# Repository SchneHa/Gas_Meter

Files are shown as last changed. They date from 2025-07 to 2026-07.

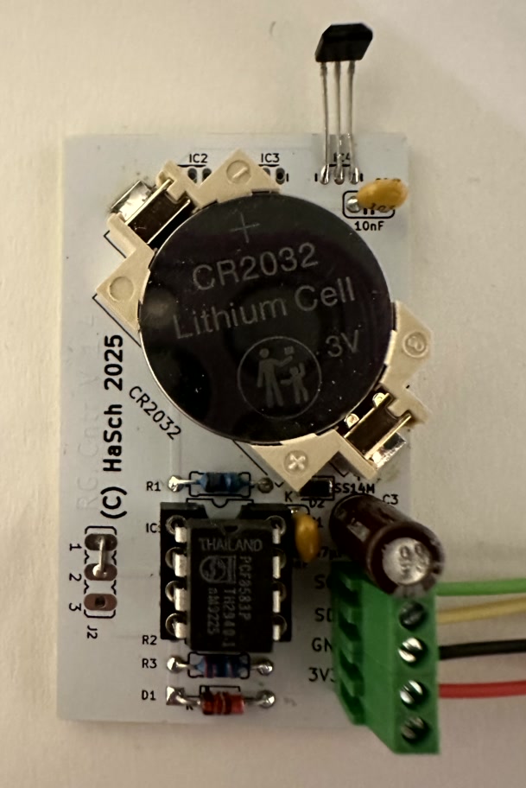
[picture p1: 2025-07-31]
Gas_Meter/pcb/V1.4/CP Gas Zähler Lesekopf.jpg

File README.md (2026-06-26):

# Gasverbrauch messen und verarbeiten 

## Funktion

Manche Gaszähler geben pro verbrauchte 10 Liter einen magnetischen Impuls ab.
Dieser Impuls wird mit einem Hall Sensor in elektrische Impulse umgewandelt, ein RTC Baustein PCF8583 arbeitet als Zähler und speichert die Zahl der Impulse im internen RAM ab.

PCB Eagle Dateien (für Version 1.3) und KiCAD Dateien (für Version 1.4) sowie Stückliste (BOM) für beide Versionen anbei.

Ich habe sowohl für die Version 1.3 als auch für die Version 1.4 noch einige Platinen übrig, bei Bedarf bitte melden:
```
PCB unbestückt: 5€
PCB mit Bauteilen: 15€
PCB fertig bestückt (ohne Knopfzelle und Hallsensor noch nicht bestückt): 20€
D1 mini ESP8266: 10€
inklusive Versand innerhalb Deutschlands
hans(dot)schneider(at)gmx(dot)ch
```

Die Daten werden mit Hilfe eines ESP8266 (z.B. Wemos D1 mini) über die I²C Schnittstelle ausgelesen und verarbeitet. 
Über das MQTT Protokoll werden die Daten an einen lokalen Broker weitergeleitet, Daten werden nicht ins Internet hochgeladen, es sei denn, man richtet die Verarbeitung über Thingspeak explizit ein.
Eine 3 Volt Knopfzelle versorgt den Baustein mit Energie und erhält die Daten bei Stromausfall. In der Version 1.4 wird der Sensor durch den ESP8266 versorgt, die Knopfzelle arbeitet als Backup Batterie.

* Diese Daten werden im RTC RAM gespeichert

1. Zählimpulse
2. Zählerstand zu Beginn der Messung (Counts=0)
3. Zählerstand zu Beginn der Abrechnungsperiode
4. monatlicher Verbrauch in m³
5. Datum und Uhrzeit des letzen Auslesens des RTC Bausteins

* Diese Daten werden über MQTT an den Broker gesendet

1. Uhrzeit 
2. Gesamtverbrauch in kWh
3. aktuelle Leistung in kW
4. Anzahl der Impulse seit Reset
5. Gesamtverbrauch in m³
6. Zählerstand zu Beginn der Messung (Counts=0) in Liter
7. Zählerstand zu Begin der Abrechnungsperiode in Liter
8. nach Bedarf monatlicher Verbrauch
9. Täglicher Verbrauch in l, kWh und m³
10. Status (OK wenn Zugriff auf den RTC Baustein möglich)

* Diese Daten/Kommandos können vom Broker an den ESP8266 gesendet werden

1. Veröffentliche den Verbrauch eines einzelnen Monats oder aller Monate von 1 to 12 
 * SYNTAX  : "Energy/Gas/command"
 * PAYLOAD : "Monat, x"
 * Wert für x: entweder 1 bis 12 für einen einzelnen Monat, oder x > 12 für alle 12 Monate
  
 2. Setze den Wert für den Verbrauch zu Beginn der Heizperiode 
 * SYNTAX  : "Energy/Gas/command"
 * PAYLOAD : "InitP, x"
 * Wert für x: Verbrauch in Litern

 3. Setze den initialen Verbrauchswert für den Counter Null 
 * SYNTAX  : "Energy/Gas/command"
 * PAYLOAD : "InitS, x"
 * Wert für x: Verbrauch in Litern

 4. Setze den initialen Wert für den Verbrauch eines einzelnen Monats  
 * SYNTAX  : "Energy/Gas/command"
 * PAYLOAD : "InitM, x ; y"
 * value for x: ausgewählter Monat
 * value for y: Verbrauch in Litern
 
 5. Setze den Wert für den Start der Abrechnungsperiode 
 * Initialisiert den RTC chip und setzt den initialen Verbrauchswert für count=0 der Abrechnungsperiode 
 * SYNTAX  : "Energy/Gas/command"
 * PAYLOAD : "InitC, x"
 * value for x: Verbrauch in Litern

 6. Setze den Tageszähler zurück auf Null 
 * Setzt den aktuellen Verbrauchswert für den Tageszähler auf 0 zurück 
 * SYNTAX  : "Energy/Gas/command"
 * PAYLOAD : "InitD"

## Vorbereitung

* in Gas_WiFi SSID und Passwort eintragen
* für ArduinoOTA (Firmware Update **O**ver **T**he **A**ir) hashed Wert eines gewählte Passortes eintragen, der Hash-Wert kann z.B. über https://hash-generieren.de/ oder https://www.md5hashgenerator.com/ oder https://www.hexhero.com/tools/sha256-hash-generator gebildet werden.    
* in Gas_MQTT IP Adresse des MQTT Broker eintragen
* ggfs. Thingspeak aktivieren und Channelnummer und Key eintragen
* Topic für MQTT an die eigenen Wünsche anpassen

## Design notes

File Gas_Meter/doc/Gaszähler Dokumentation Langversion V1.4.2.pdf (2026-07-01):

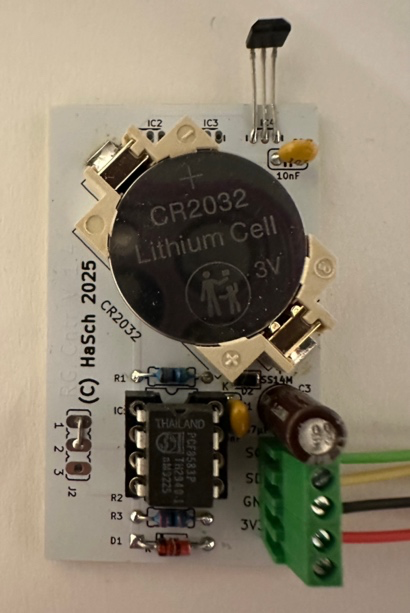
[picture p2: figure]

Abbildung 1: Gaszähler
Lesekopf V1.4

Gaszähler auslesen
Daten gegen Verlust absichern

Anders als Smart Meter zum Messen der elektrischen Arbeit speichern herkömmliche Gaszähler den gemessenen Verbrauch mechanisch in einem Zählwerk.

Ein direktes Auslesen des Verbrauchs ist etwa mit Hilfe einer Kamera und Bildanalyse möglich, der Aufwand aber recht hoch.

Viele Gaszähler geben einen magnetischen Impuls pro Umdrehung der 2. oder 3. Stelle hinter dem Komma, ab. Meistens ist das 1 Impuls pro 10 Liter (2. Stelle). In der Regel steht das auch auf dem Typenschild.

Das Zählen der Impulse erlaubt also, den Verbrauch zu ermitteln, allerdings nicht den absoluten Wert, sondern nur den Wert seit Beginn der Zählung.

Im Folgenden wird ein Lesekopf mit Speichermöglichkeit und Auswertung über einen ESP8266 Mikrocontroller beschrieben.

Hardware:

Um die Zählimpulse auch bei einem Stromausfall zu speichern, fiel die Wahl auf einen RTC CMOS Baustein, der auch als Zähler eingesetzt werden kann und 240 Bytes an RAM bietet:

PCF8583 von Philips

Der PCF8583 ist zwar recht alt aber immer noch in Stückzahlen im DIL8 Gehäuse zu haben.
Der Baustein hat ein I²C Interface und kann einfach über einen ESP8266 ausgelesen werden, der dann auch die weitere Verarbeitung übernimmt.
Mit einer Stromaufnahme von typisch 10µA bei 5 Volt und SCL inaktiv reicht eine CR2032 3-Volt Knopfzelle für lange Zeit. Das Auslesen über I²C ist bis hinunter zu 2,5 Volt Betriebsspannung möglich, der interne Zähler funktioniert laut Datenblatt sogar bis zu 1 Volt.
Für die Erfassung der Zählimpulse kann entweder ein Reed Schalter oder ein Hall-Effekt Sensor verwendet werden. Da aber Reed Schalter zum Prellen neigen und aufwendig hardwaremäßig entprellt werden müssten, fiel die Wahl auf einen Hall-Effekt Sensor. Auch hier sind die Anforderungen niedrige Stromaufnahme und Funktion bis herunter zu 2,5 Volt Betriebsspannung.

AH3661UA 2.4 - 5.4 V/DC Messbereich: -0.007 - +0.007

Mit einer Stromaufnahme von typisch 2µA im Ruhezustand bei 2,4 Volt und einem pull-up Widerstand von 0,5 bis 1 MOhm sind die Anforderungen voll erfüllt. Zusammen mit recht hochohmigen pull-up Widerständen für SDA und SCL war die gemessene Stromaufnahme bei der Musterplatine zwischen 8 und 14µA.

Eine kleine Platine mit Standard Bauteilen kann so in die Aufnahme unterhalb des Zählwerkes gesteckt werden, dass der Sensor genau unter der Stelle mit dem Magneten positioniert ist.

Zum Auslesen der Daten wird ein ESP8266 verwendet, der über das lokale WiFi Netzwerk die Daten zur Auswertung weiterreicht.

Software:

Es liegt nahe, den Speicher des RTC-Bausteins für mehr als das Abspeichern der gezählten Impulse zu nutzen, auf diese Weise kann man die Daten der Abrechnungsperiode nachhalten.
Für die Programmierung des ESP8266 habe ich die Arduino IDE 2.3.9 und die Bibliotheken Wire, time, Esp8266WiFi, PicoMQTT, Thingspeak und ArduinoOTA verwendet, alle lassen sich über die Bibliotheksverwaltung herunterladen, soweit nicht schon vorhanden

Hier ist das Speichermodell für das CMOS RAM (wurde in der Version 1.4.2 aus Gründen des knappen Speicherplatzes verschlankt):

ADDRESS_OLD_COUNTER | //hält den letzten Stand der Auslesung mit I²C
ADDRESS_START_METER | //Zählerstand beim Start mit Counts = 0
ADDRESS_START_METER_FLAG //Gültigkeitsprüfung für den Startwert
ADDRESS_START_PERIOD | //Zählerstand zum Beginn der Abrechungsperiode
ADDRESS_START_PERIOD_FLAG //Gültigkeitsprüfung des Startwertes der Heizperiode ADDRESS_DAY_START_COUNT //Startdatum des letzten Tageszählers
ADDRESS_DAY_DATE | //Datum für Ermittlung des Tageswechsels
ADDRESS_DAY_INITIALIZED | //1 byte, Tageszähler 0 = nicht initialisiert, 1 = initialisiert
ADDRESS_DAY_STATE | //aktueller Zustand des Tageszählers
ADDRESS_MONTH_VALID | // Gültigkeitsprüfung der Monatswerte
ADDRESS_MONTH_01 | //Zählerstand zum Beginn des ersten Monats, insgesamt
| 12 x 2 Byte = 24 Byte für Monat 1 bis Monat 12

Die Monatswerte sind besonders interessant, weil man damit überprüfen kann, ob der monatliche Abschlag noch ausreichend oder zu hoch ist, im Vergleich mit den Vorjahreswerten kann man auch den Erfolg von Energiesparmaßnahmen beurteilen. In der vorliegenden Version werden nun nicht mehr die Monatszählerstände gesichert, sondern die tatsächlichen Verbrauchswerte. Auch die Tagesstände werden ermittelt und über MQTT gesendet. Der Gesamtwert Total_kWh gibt nun nicht mehr den Wert bezogen auf die Counts seit Null wieder sondern des Gesamtwert unter Berücksichtigung des eingegebenen Startwertes. Dies ist logischer und für den Nutzer von größerem Interesse.

Zum Debuggen gibt es nun eine Ausgabe der wichtigsten Werte unter Energy/Gas/debug. Dies hilft, Fehler im Programmablauf zu erkennen und zu beseitigen.

ArduinoOTA rundet das Programm ab. Es dient dazu, Firmwareupdates drahtlos an das ESP8266-Board zu senden (Over The Air). Es muss also zum Aktualisieren nicht mehr von der Schaltung getrennt werden. Das dazu erforderliche Passwort ist s3uErNgW, es ist im Code nicht im Klartext zu finden sondern als hashed Passphrase.

Die Werte für Start_Meter und Start_Period können über MQTT gesetzt werden, ein Senden von Start_Meter setzt den Zähler auf Null, so können Zähler und RTC synchronisiert werden. In der vorliegenden Version ist ein Tageszähler eingebaut der auch während des Tages zurückgesetzt werden kann. Dies ist über das neu eingebaute Kommando InitD möglich, das über MQTT an Energy/Gas/command gesendet wird. Zur Logik der Zählerroutine siehe auch die Übersichten im Anhang.

Die Daten werden über MQTT zur weiteren Auswertung / Anzeige und Thingspeak zur einfachen Visualisierung weitergereicht.

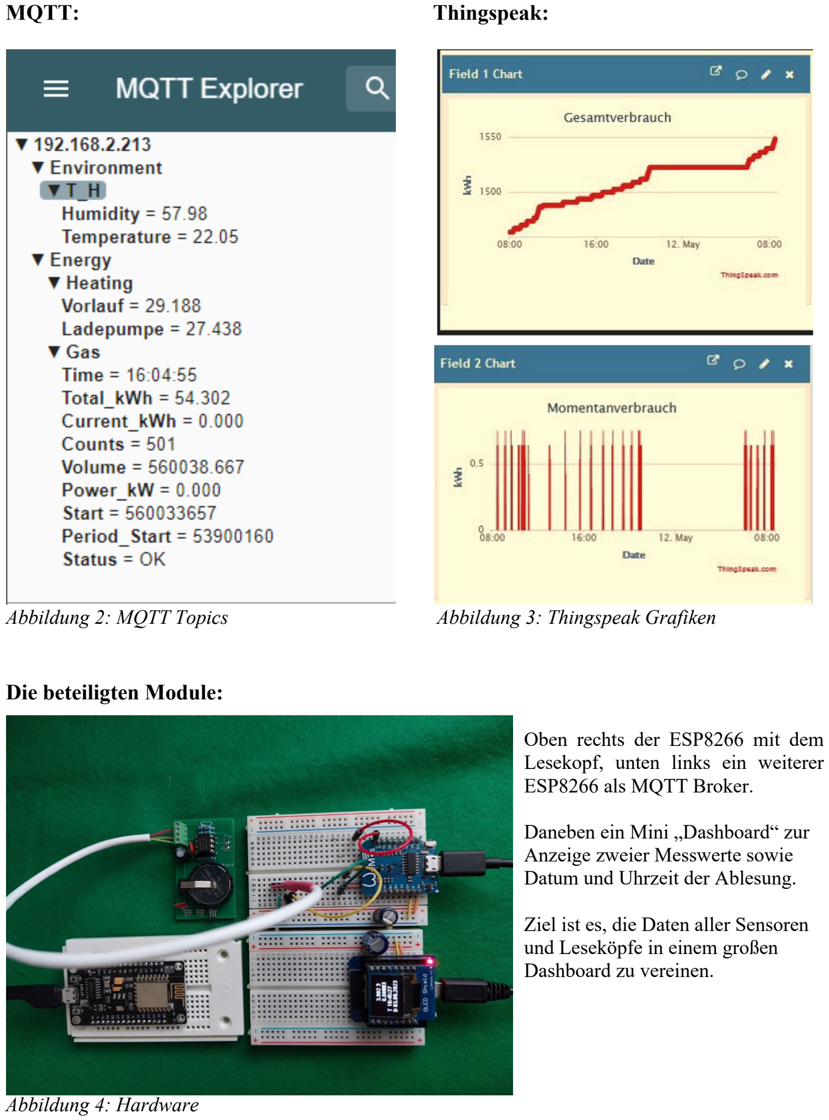
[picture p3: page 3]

MQTT: | Thingspeak:
Abbildung 2: MQTT Topics | Abbildung 3: Thingspeak Grafiken

Die beteiligten Module:

| Oben rechts der ESP8266 mit dem Lesekopf, unten links ein weiterer ESP8266 als MQTT Broker.
| Daneben ein Mini „Dashboard“ zur Anzeige zweier Messwerte sowie Datum und Uhrzeit der Ablesung.
| Ziel ist es, die Daten aller Sensoren und Leseköpfe in einem großen Dashboard zu vereinen.

Abbildung 4: Hardware

Der „Einbau“:

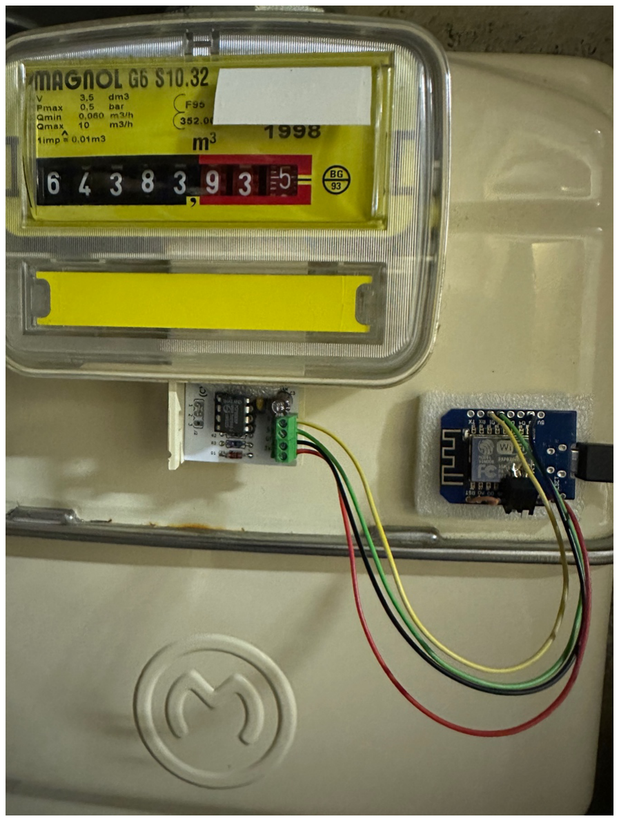
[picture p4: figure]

Abbildung 5: Einbau

Der ESP wird aus einem kleinen Netzteil versorgt, zum Stromsparen in den Deep Sleep Modus versetzt und alle 2 Minuten aufgeweckt. Dabei versorgt der ESP auch den Sensor, bei Stromausfall übernimmt die Knopfzelle die Versorgung.

Der Mikrocontroller hat keine weiteren Bedienelemente.
Eine Brücke von Reset auf D0 ist notwendig, um das Aufwachen nach dem Deep Sleep zu ermöglichen, eine Brücke von D7 nach GND ruft beim nächsten Boot bzw. nächsten Loop die Init-Routine für den RTC Baustein auf. Dies ist nur bei der ersten Inbetriebnahme oder beim Ausfall der Versorgung über die Knopfzelle notwendig. MQTT meldet in diesem Fall einen Fehler, da dann keine Kommunikation mit dem RTC mehr möglich ist.

Eine weitere Brücke von D6 nach GND verhindert den Deep Sleep, so dass über MQTT die Startwerte für die Abrechnungsperiode und der Startwert für den Verbrauch nach Rücksetzen des Zählers gesendet werden können.
In meinem Setup sind dies die Topics Energy/Gas/command/InitS für den Startwert Verbrauch und Energy/Gas/command/InitP für den Startwert der Abrechnungsperiode, jeweils als ganzzahliger Wert in Litern.
Über Energy/Gas/command/InitM können die Verbrauchswerte für einzelne oder alle Monate abgerufen werden.

Beide Brücken für D6 und D7 sind für den Normalbetrieb nicht notwendig.

Schlussbemerkung:

Der Aufbau mit dem RTC Baustein und dem ESP8266 läuft seit langer Zeit ohne Probleme, auch das Abstecken des Controllers für längere Zeit hat nicht zum Datenverlust geführt, nur die zeitliche Zuordnung der Impulse geht verloren, diese werden der Periode zwischen Abstecken und Wiederanschließen zugeordnet. Wenn diese Zeit nicht über den Monatswechsel hinausgeht, ist die Zurechnung zum „richtigen“ Monat gegeben.

Die über MQTT gesendeten Werte für den Gesamtzähler und den Tageszähler werden bei mir durch mein P1meter (https://github.com/SchneHa/P1-WiFi-Gateway) als MQTT-Subscription abonniert und im Webinterface des P1meters angezeigt. Dadurch sind die Werte für elektrische Energie und Gas an einer Stelle ablesbar.

Was gibt es noch zu tun bzw. zu verbessern:

- Um die Daten langfristig lokal abzuspeichern, bietet sich ein EEPROM an.
- Ein Gehäuse für den Lesekopf, welches dann in die Öffnung unterhalb des Zählwerkes passt, würde das Ganze professioneller machen.
- Statt den Verbrauch in kWh pro Tag oder Monat wäre eine Grafik mit Euro pro Stunde auch sinnvoll, das würde die Kosten der Wärme in der Wohnung immer sichtbar machen und die Wirkung von Energiesparmaßnahmen könnte in Verbindung von Außen- und Innentemperatur besser beurteilt werden.

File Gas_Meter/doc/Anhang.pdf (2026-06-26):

## Logik der Zählerroutine

Zustände

### 1. Normalbetrieb

- manual_reset_active = false
- day_start_count enthält den Startwert des aktuellen Kalendertags.
- daily_count = new_count - day_start_count.
- Beim Mitternachtswechsel wird day_start_count auf den aktuellen new_count gesetzt.

### 2. Manueller Reset mit InitD

- manual_day_start = new_count
- manual_reset_active = true
- day_start_count = 0
- daily_count = 0
In diesem Zustand darf die Tageswechsel-Logik day_start_count nicht überschreiben.

### 3. Nach dem ersten neuen Impuls nach InitD

- daily_count = new_count - manual_day_start
- Der Tageszähler läuft ab jetzt weiter ab 0.
- day_start_count bleibt 0, solange die manuelle Reset-Phase aktiv ist.

### 4. Mitternacht während manuellem Reset

- Solange manual_reset_active = true, bleibt die manuelle Logik führend.
- Der normale Tageswechsel darf keinen neuen day_start_count setzen.
- Sonst würde der manuelle Tagesstart wieder überlagert.

### 5. Board-Reset / Neustart

- Die im RAM gespeicherten Werte werden beim Start neu eingelesen.
- Wenn der nichtflüchtig gesicherte Zustand erhalten ist, läuft der Sketch mit den letzten Werten weiter.
- Wenn ein Hardware-Reset ausgelöst wurde, kann der Zähler explizit neu initialisiert werden.

Merksatz
- day_start_count gehört zum normalen Tageswechsel.
- manual_day_start gehört zum manuellen Reset.
- Nie beide gleichzeitig als Berechnungsbasis verwenden.

Ablauf als Kurzlogik

InitD
→ manual_day_start = new_count → manual_reset_active = true
→ daily_count = 0

nächster Impuls
→ daily_count = new_count - manual_day_start

Mitternacht ohne manuellen Reset
→ day_start_count = new_count
→ daily_count = 0

Board-Reset
→ Werte aus RAM laden
→ Zustand abhängig von gespeichertem Flag fortsetzen

Zustand | manual_day_start | day_start_count | daily_count | Verhalten
Normalbetrieb | egal | Tagesstart des Kalendertags | new_count -day_start_count | Zählt ganz normal pro Tag weiter.
Direkt nach InitD | aktueller new_count | 0 | 0 | Tageszähler wird auf 0 gesetzt und bleibt dort zunächst stehen.
Erster neuer Impuls nach InitD | alter Resetwert | 0 | new_count -manual_day_start | Zählt ab 1 weiter, zu springen.
Weitere Impulse nach InitD | alter Resetwert | 0 | new_count -manual_day_start | Läuft sauber weiter, solange die manuelle Reset-Phase aktiv ist.
Mitternacht im Normalbetrieb | egal | neuer new_count | 0 | Tagesstart wird auf den aktuellen Gesamtzähler gesetzt.
Mitternacht während manuellem Reset | alter Resetwert | 0 | weiter nach manual_day_start | Der normale Tageswechsel darf die manuelle Reset-Basis nicht überschreiben.
Board-Reset / Neustart | abhängig vom gespeicherten Zustand | aus Speicher geladen oder 0 | neu berechnet | Der Sketch nimmt, soweit gespeichert, die letzten Werte wieder auf.

ohne auf new_count

## Logik als Ablauf

1. InitD
→ manual_day_start = new_count → manual_reset_active = true
→ daily_count = 0
→ day_start_count = 0
2. Nächster Impuls
→ daily_count = new_count - manual_day_start
3. Normaler Tageswechsel
→ day_start_count = new_count
→ daily_count = 0
4. Board-Reset
→ gespeicherte Werte laden
→ Zustand je nach Flags fortsetzen

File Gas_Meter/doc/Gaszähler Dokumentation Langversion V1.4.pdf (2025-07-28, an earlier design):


Abbildung 1: Gaszähler
Lesekopf V1.4

Gaszähler auslesen
Daten gegen Verlust absichern

Anders als Smart Meter zum Messen der elektrischen Arbeit speichern herkömmliche Gaszähler den gemessenen Verbrauch mechanisch in einem Zählwerk.

Ein direktes Auslesen des Verbrauchs ist etwa mit Hilfe einer Kamera und Bildanalyse möglich, der Aufwand aber recht hoch.

Viele Gaszähler geben einen magnetischen Impuls pro Umdrehung der 2. oder 3. Stelle hinter dem Komma, ab. Meistens ist das 1 Impuls pro 10 Liter (2. Stelle). In der Regel steht das auch auf dem Typenschild.

Das Zählen der Impulse erlaubt also, den Verbrauch zu ermitteln, allerdings nicht den absoluten Wert, sondern nur den Wert seit Beginn der Zählung.

Im Folgenden wird ein Lesekopf mit Speichermöglichkeit und Auswertung über einen ESP8266 Mikrocontroller beschrieben.

Hardware:

Um die Zählimpulse auch bei einem Stromausfall zu speichern, fiel die Wahl auf einen RTC CMOS Baustein, der auch als Zähler eingesetzt werden kann und 240 Bytes an RAM bietet:

PCF8583 von Philips

Der PCF8583 ist zwar recht alt aber immer noch in Stückzahlen im DIL8 Gehäuse zu haben.
Der Baustein hat ein I²C Interface und kann einfach über einen ESP8266 ausgelesen werden, der dann auch die weitere Verarbeitung übernimmt.
Mit einer Stromaufnahme von typisch 10µA bei 5 Volt und SCL inaktiv reicht eine CR2032 3-Volt Knopfzelle für lange Zeit. Das Auslesen über I²C ist bis hinunter zu 2,5 Volt Betriebsspannung möglich, der interne Zähler funktioniert laut Datenblatt sogar bis zu 1 Volt.
Für die Erfassung der Zählimpulse kann entweder ein Reed Schalter oder ein Hall Sensor verwendet werden. Da aber Reed Schalter zum Prellen neigen und aufwendig hardwaremäßig entprellt werden müssten, fiel die Wahl auf einen Hall Sensor. Auch hier sind die Anforderungen niedrige Stromaufnahme und Funktion bis herunter zu 2,5 Volt Betriebsspannung.

AH3661UA 2.4 - 5.4 V/DC Messbereich: -0.007 - +0.007

Mit einer Stromaufnahme von typisch 2µA im Ruhezustand bei 2,4 Volt und einem pull-up Widerstand von 0,5 bis 1 MOhm sind die Anforderungen voll erfüllt. Zusammen mit recht hochohmigen pull-up Widerständen für SDA und SCL war die gemessene Stromaufnahme bei der Musterplatine zwischen 8 und 14µA.

Eine kleine Platine mit Standard Bauteilen kann so in die Aufnahme unterhalb des Zählwerkes gesteckt werden, dass der Sensor genau unter der Stelle mit dem Magneten positioniert ist.

Zum Auslesen der Daten wird ein ESP8266 verwendet, der über das lokale WiFi Netzwerk die Daten zur Auswertung weiterreicht.

Software:

Es liegt nahe, den Speicher des RTC Bausteins für mehr als das Abspeichern der gezählten Impulse zu nutzen, auf diese Weise kann man die Daten der Abrechnungsperiode nachhalten.
Für die Programmierung des ESP8266 habe ich die Arduino IDE 2.1.1 und die Bibliotheken Wire, time, Esp8266WiFi, PicoMQTT und Thingspeak verwendet, alle lassen sich über die Bibliotheksverwaltung herunterladen, soweit nicht schon vorhanden

Hier ist das Speichermodell für das CMOS RAM:
ADDRESS_OLD_COUNTER | // hält den letzten Stand der Auslesung mit I²C
ADDRESS_OLD_TIME | // Uhrzeit der letzten Auslesung mit I²C
ADDRESS_OLD_DATE | // Datum der letzten Auslesung mit I²C
ADDRESS_SAVE_COUNT | // Impulse seit der letzten Übermittlung
ADDRESS_START_METER | // Zählerstand beim Start mit Counts = 0
ADDRESS_START_PERIOD | // Zählerstand zum Beginn der Abrechungsperiode
ADDRESS_MONTH_01 | // Zählerstand zum Beginn des ersten Monats
| weitere 11 Adressen bis Monat 12

Die Monatswerte sind besonders interessant, weil man damit überprüfen kann, ob der monatliche Abschlag noch ausreichend oder zu hoch ist, im Vergleich mit den Vorjahreswerten kann man auch den Erfolg von Energiesparmaßnahmen beurteilen.

Die Werte für Start_Meter und Start_Period können über MQTT gesetzt werden, ein Senden von Start_Meter setzt den Zähler auf Null, so können Zähler und RTC synchronisiert werden.

Die Daten werden über MQTT zur weiteren Auswertung / Anzeige und Thingspeak zur einfachen Visualisierung weitergereicht.

MQTT: | Thingspeak:

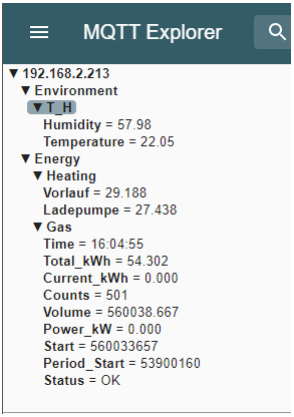
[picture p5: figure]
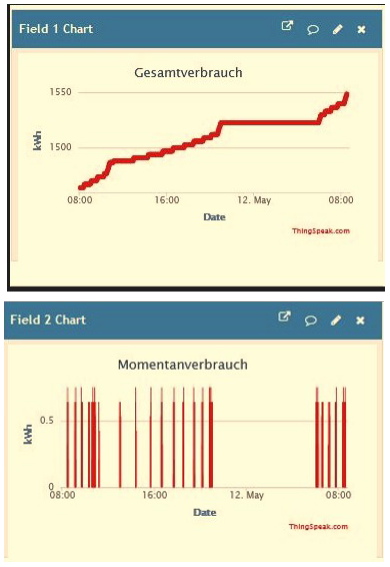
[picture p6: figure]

Abbildung 2: MQTT Topics | Abbildung 3: Thingspeak Grafiken

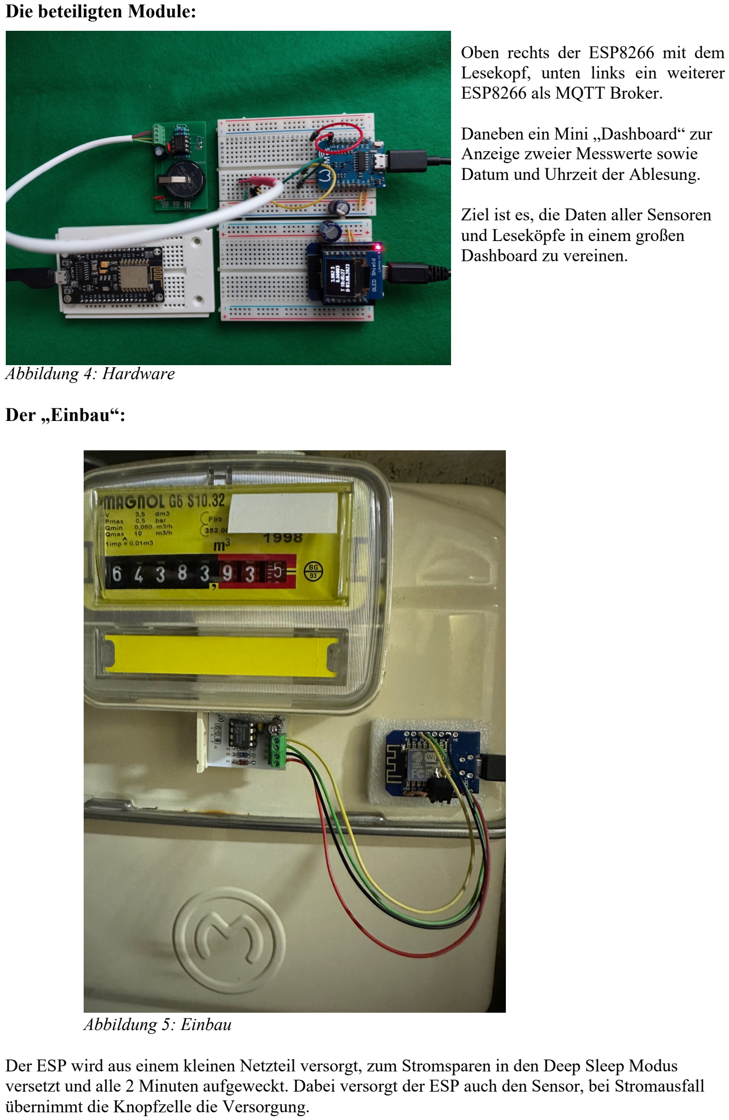
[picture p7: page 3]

Die beteiligten Module:

Oben rechts der ESP8266 mit dem Lesekopf, unten links ein weiterer ESP8266 als MQTT Broker.

Daneben ein Mini „Dashboard“ zur Anzeige zweier Messwerte sowie Datum und Uhrzeit der Ablesung.

Ziel ist es, die Daten aller Sensoren und Leseköpfe in einem großen Dashboard zu vereinen.

Abbildung 4: Hardware

Der „Einbau“:

Abbildung 5: Einbau

Der ESP wird aus einem kleinen Netzteil versorgt, zum Stromsparen in den Deep Sleep Modus versetzt und alle 2 Minuten aufgeweckt. Dabei versorgt der ESP auch den Sensor, bei Stromausfall übernimmt die Knopfzelle die Versorgung.

Der Mikrocontroller hat keine weiteren Bedienelemente.
Eine Brücke von Reset auf D0 ist notwendig, um das Aufwachen nach dem Deep Sleep zu ermöglichen, eine Brücke von D7 nach GND ruft beim nächsten Boot bzw. nächsten Loop die Init Routine für den RTC Baustein auf. Dies ist nur bei der ersten Inbetriebnahme oder beim Ausfall der Versorgung über die Knopfzelle notwendig. MQTT meldet in diesem Fall einen Fehler, da dann keine Kommunikation mit dem RTC mehr möglich ist.

Eine weitere Brücke von D6 nach GND verhindert den Deep Sleep, so dass über MQTT die Startwerte für die Abrechnungsperiode und der Startwert für den Verbrauch nach Rücksetzen des Zählers gesendet werden können.
In meinem Setup sind dies die Topics Energy/Gas/InitS für den Startwert Verbrauch und Energy/Gas/InitP für den Startwert der Abrechnungsperiode, jeweils als ganzzahliger Wert in Litern.

Beide Brücken für D6 und D7 sind für den Normalbetrieb nicht notwendig.

Schlussbemerkung:

Der Aufbau mit dem RTC Baustein und dem ESP8266 läuft seit langer Zeit ohne Probleme, auch das Abstecken des Controllers für längere Zeit hat nicht zum Datenverlust geführt, nur die zeitliche Zuordnung der Impulse geht verloren, diese werden der Periode zwischen Abstecken und Wiederanschließen zugeordnet. Wenn diese Zeit nicht über den Monatswechsel hinausgeht, ist die Zurechnung zum „richtigen“ Monat gegeben.

Was gibt es noch zu tun bzw. zu verbessern:

- Um die Daten langfristig lokal abzuspeichern, bietet sich ein EEPROM an.
- Ein Gehäuse für den Lesekopf, welches dann in die Öffnung unterhalb des Zählwerkes passt, würde das Ganze professioneller machen.
- Statt den Verbrauch in kWh pro Tag oder Monat wäre eine Grafik mit Euro pro Stunde auch sinnvoll, das würde die Kosten der Wärme in der Wohnung immer sichtbar machen und die Wirkung von Energiesparmaßnahmen könnte in Verbindung von Außen- und Innentemperatur besser beurteilt werden.

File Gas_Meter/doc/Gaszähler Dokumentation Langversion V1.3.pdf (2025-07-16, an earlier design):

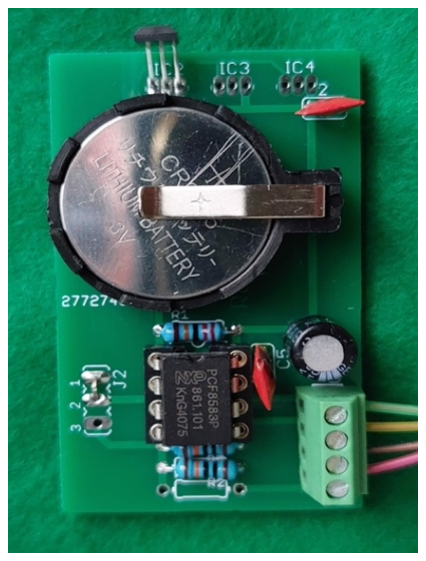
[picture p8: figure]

Abbildung 1: Gaszähler
Lesekopf V1.3

Gaszähler auslesen
Daten gegen Verlust absichern

Anders als Smart Meter zum Messen der elektrischen Arbeit speichern herkömmliche Gaszähler den gemessenen Verbrauch mechanisch in einem Zählwerk.

Ein direktes Auslesen des Verbrauchs ist etwa mit Hilfe einer Kamera und Bildanalyse möglich, der Aufwand aber recht hoch.

Viele Gaszähler geben einen magnetischen Impuls pro Umdrehung der 2. oder 3. Stelle hinter dem Komma, ab. Meistens ist das 1 Impuls pro 10 Liter (2. Stelle). In der Regel steht das auch auf dem Typenschild.

Das Zählen der Impulse erlaubt also, den Verbrauch zu ermitteln, allerdings nicht den absoluten Wert, sondern nur den Wert seit Beginn der Zählung.

Im Folgenden wird ein Lesekopf mit Speichermöglichkeit und Auswertung über einen ESP8266 Mikrocontroller beschrieben.

Hardware:

Um die Zählimpulse auch bei einem Stromausfall zu speichern, fiel die Wahl auf einen RTC CMOS Baustein, der auch als Zähler eingesetzt werden kann und 240 Bytes an RAM bietet:

PCF8583 von Philips

Der PCF8583 ist zwar recht alt aber immer noch in Stückzahlen im DIL8 Gehäuse zu haben.
Der Baustein hat ein I²C Interface und kann einfach über einen ESP8266 ausgelesen werden, der dann auch die weitere Verarbeitung übernimmt.
Mit einer Stromaufnahme von typisch 10µA bei 5 Volt und SCL inaktiv reicht eine CR2032 3-Volt Knopfzelle für lange Zeit. Das Auslesen über I²C ist bis hinunter zu 2,5 Volt Betriebsspannung möglich, der interne Zähler funktioniert laut Datenblatt sogar bis zu 1 Volt.
Für die Erfassung der Zählimpulse kann entweder ein Reed Schalter oder ein Hall Sensor verwendet werden. Da aber Reed Schalter zum Prellen neigen und aufwändig hardwaremäßig entprellt werden müssten, fiel die Wahl auf einen Hall Sensor. Auch hier sind die Anforderungen niedrige Stromaufnahme und Funktion bis herunter zu 2,5 Volt Betriebsspannung.

AH3661UA 2.4 - 5.4 V/DC Messbereich: -0.007 - +0.007

Mit einer Stromaufnahme von typisch 2µA im Ruhezustand bei 2,4 Volt und einem pull-up Widerstand von 0,5 bis 1 MOhm sind die Anforderungen voll erfüllt. Zusammen mit recht hochohmigen pull-up Widerständen für SDA und SCL war die gemessene Stromaufnahme bei der Musterplatine zwischen 8 und 14µA.

Eine kleine Platine mit Standard Bauteilen kann so in die Aufnahme unterhalb des Zählwerkes gesteckt werden, dass der Sensor genau unter der Stelle mit dem Magneten positioniert ist.

Zum Auslesen der Daten wird ein ESP8266 verwendet, der über das lokale WiFi Netzwerk die Daten zur Auswertung weiterreicht.

Software:

Es liegt nahe, den Speicher des RTC Bausteins für mehr als das Abspeichern der gezählten Impulse zu nutzen, auf diese Weise kann man die Daten der Abrechnungsperiode nachhalten.
Für die Programmierung des ESP8266 habe ich die Arduino IDE 2.1.1 und die Bibliotheken Wire, time, Esp8266WiFi, PicoMQTT und Thingspeak verwendet, alle lassen sich über die Bibliotheksverwaltung herunterladen, soweit nicht schon vorhanden

Hier ist das Speichermodell für das CMOS RAM:
ADDRESS_OLD_COUNTER | // hält den letzten Stand der Auslesung mit I²C
ADDRESS_OLD_TIME | // Uhrzeit der letzten Auslesung mit I²C
ADDRESS_OLD_DATE | // Datum der letzten Auslesung mit I²C
ADDRESS_SAVE_COUNT | // Impulse seit der letzten Übermittlung
ADDRESS_START_METER | // Zählerstand beim Start mit Counts = 0
ADDRESS_START_PERIOD | // Zählerstand zum Beginn der Abrechungsperiode
ADDRESS_MONTH_01 | // Zählerstand zum Beginn des ersten Monats
| weitere 11 Adressen bis Monat 12

Die Monatswerte sind besonders interessant, weil man damit überprüfen kann, ob der monatliche Abschlag noch ausreichend oder zu hoch ist, im Vergleich mit den Vorjahreswerten kann man auch den Erfolg von Energiesparmaßnahmen beurteilen.

Die Werte für Start_Meter und Start_Period können über MQTT gesetzt werden, ein Senden von Start_Meter setzt den Zähler auf Null, so können Zähler und RTC synchronisiert werden.

Die Daten werden über MQTT zur weiteren Auswertung / Anzeige und Thingspeak zur einfachen Visualisierung weitergereicht.

MQTT: | Thingspeak:

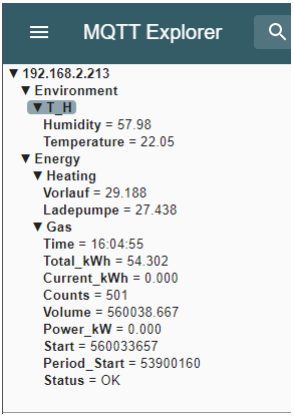
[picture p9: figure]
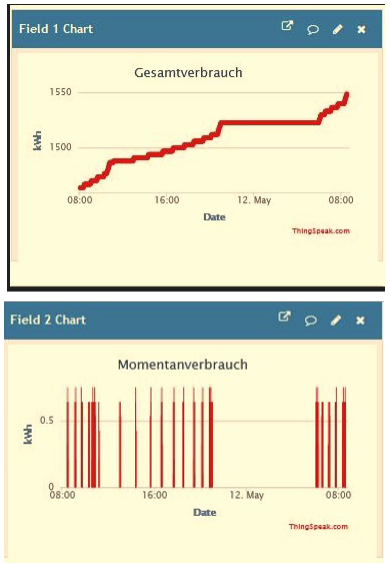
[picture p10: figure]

Abbildung 2: MQTT Topics | Abbildung 3: Thingspeak Grafiken

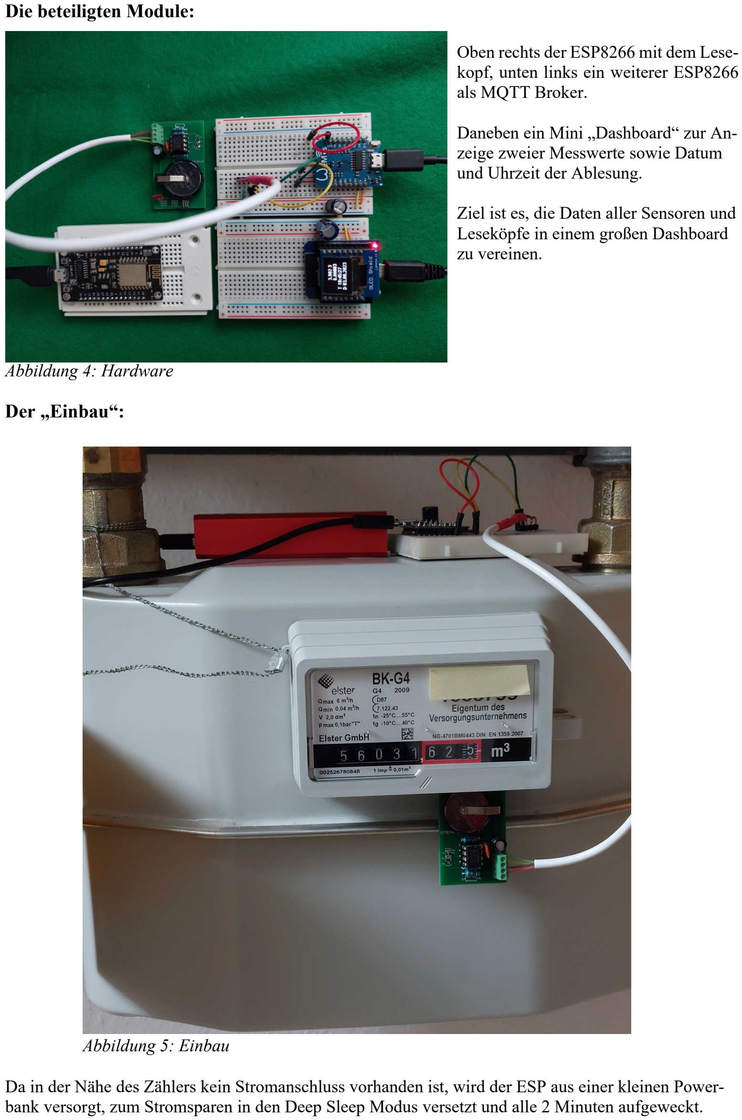
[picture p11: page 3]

Die beteiligten Module:

Oben rechts der ESP8266 mit dem Lesekopf, unten links ein weiterer ESP8266 als MQTT Broker.

Daneben ein Mini „Dashboard“ zur Anzeige zweier Messwerte sowie Datum und Uhrzeit der Ablesung.

Ziel ist es, die Daten aller Sensoren und Leseköpfe in einem großen Dashboard zu vereinen.

Abbildung 4: Hardware

Der „Einbau“:

Abbildung 5: Einbau

Da in der Nähe des Zählers kein Stromanschluss vorhanden ist, wird der ESP aus einer kleinen Powerbank versorgt, zum Stromsparen in den Deep Sleep Modus versetzt und alle 2 Minuten aufgeweckt.

Der Mikrocontroller hat keine weiteren Bedienelemente.
Eine Brücke von Reset auf D0 ist notwendig, um das Aufwachen nach dem Deep Sleep zu ermöglichen, eine Brücke von D7 nach GND ruft beim nächsten Boot bzw. nächsten Loop die Init Routine für den RTC Baustein auf. Dies ist nur bei der ersten Inbetriebnahme oder beim Ausfall der Versorgung über die Knopfzelle notwendig. MQTT meldet in diesem Fall einen Fehler, da dann keine Kommunikation mit dem RTC mehr möglich ist.

Eine weitere Brücke von D6 nach GND verhindert den Deep Sleep, so dass über MQTT die Startwerte für die Abrechnungsperiode und der Startwert für den Verbrauch nach Rücksetzen des Zählers gesendet werden können.
In meinem Setup sind dies die Topics Energy/Gas/InitS für den Startwert Verbrauch und Energy/Gas/InitP für den Startwert der Abrechnungsperiode, jeweils als ganzzahliger Wert in Litern.

Beide Brücken für D6 und D7 sind für den Normalbetrieb nicht notwendig.

Schlussbemerkung:

Der Aufbau mit dem RTC Baustein und dem ESP8266 läuft seit langer Zeit ohne Probleme, auch das Abstecken des Controllers für längere Zeit hat nicht zum Datenverlust geführt, nur die zeitliche Zuordnung der Impulse geht verloren, diese werden der Periode zwischen Abstecken und Wiederanschließen zugeordnet. Wenn diese Zeit nicht über den Monatswechsel hinausgeht, ist die Zurechnung zum „richtigen“ Monat gegeben.

Was gibt es noch zu tun bzw. zu verbessern:

- Um die Daten langfristig lokal abzuspeichern, bietet sich ein EEPROM an.
- Ein Gehäuse für den Lesekopf, welches dann in die Öffnung unterhalb des
Zählwerkes passt, würde das Ganze professioneller machen.
- Statt den Verbrauch in kWh pro Tag oder Monat wäre eine Grafik mit Euro pro Stunde auch sinnvoll, das würde die Kosten der Wärme in der Wohnung immer sichtbar machen und die Wirkung von Energiesparmaßnahmen könnte in Verbindung von Außen- und Innentemperatur besser beurteilt werden.

Warum habe ich das alles gemacht? Weil ich ein Bastler bin!

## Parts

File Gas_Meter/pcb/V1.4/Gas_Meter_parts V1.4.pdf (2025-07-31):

Gas Zähler
Stückliste und Board
Part | Value | Device | Package
C1 | 10nF | C-EU025-024X044 | C025-024X044
C2 | 10nF | C-EU025-024X044 | C025-024X044
C3 | 47µF | CPOL-EUE2.5-5 | E2,5-5
D1 | 1N4148 | Diode_THT | DO-34
D2 | SS14M | Diode_SMD | Handsolder_0805
GND | Note(1) | 2,54/1,0 | 2,54/1,0
IC1 | PCF8583P | PCF8583P | DIL08
IC2 | AH3661UA | AH3661UA | SIP3-UA
IC3, IC4 Note(2)
J2 | Note(3) | JP2E | JP2
R1 | 470k | R-EU_0204/7 | 0204/7
R2 | 220k | R-EU_0204/7 | 0204/7
R3 | 220k | R-EU_0204/7 | 0204/7
VDD | Note(1) | 2,54/1,0 | 2,54/1,0
X2 | | MPT4 | 4POL254

Note(1)
VDD / GND sind Anschlusspads für einen CR2032 Batterie-Halter Keystone_1060_1x2032, z.B. Pollin.de 273530 oder 273528

Note(2)
Hall Sensor AH3661UA (bipolar, low Power, VCC ab 2,4 Volt) nur 1 mal an passender Stelle einsetzen

Note(3)
Jumper 2 wählt die Adresse des PCF8583
Brücke 1—2 : Adresse 0x50

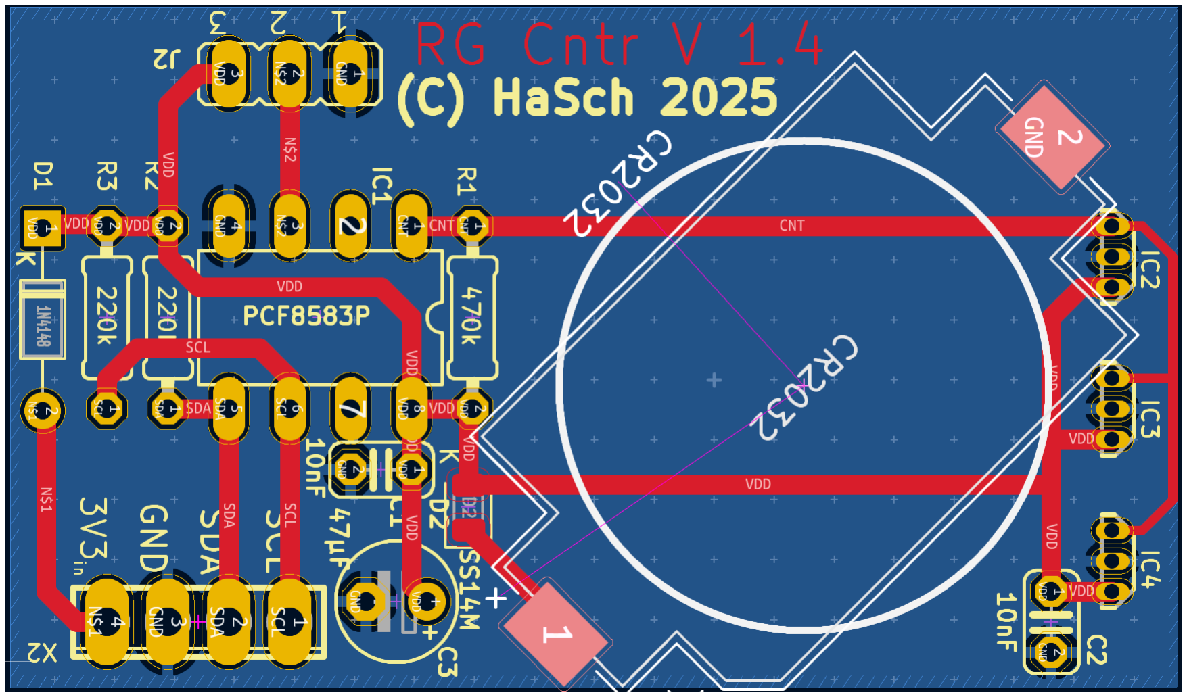
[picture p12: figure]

V | G | S | S
D | N | D C
D | D | A L
Zusammenbau

Alle Bauteile werden von der bedruckten Seite bestückt.

Zunächst D2, dann die Widerstände und D1, dann C1 und C2, sinnvollerweise eine IC Fassung für IC1, dann C3 und X2.

Sichtprüfung, erst dann der Batteriehalter, Polarität beachten!

Nun probeweise eine CR2032 Zelle einsetzen, Spannung an der IC Fassung messen, Pin 4 muss auf GND liegen, an Pin 8 muss die Versorgungsspannung VDD anliegen, die muss auch an Pin 1 zu finden sein, ebenso an dem Pin 1 des Hall Sensors, durch den Spannungsabfall an R1 wird diese Spannung dort etwas niedriger sein als an Pin 8 von IC1, das hängt vom Innenwiderstand des Messgerätes ab!

CR2032 wieder entfernen, Hall Sensor an der passenden Stelle einlöten. Die richtige Stelle ist die, die bei eingesetzter Platine genau unter der zweiten Dezimalstelle des Zählers sitzt.
Das Löten ist hier wegen der geringen Abstände der Anschlussdrähte etwas kniffelig, Lötzinn sparsam einsetzen, am besten ist hier 0,5 mm Durchmesser des Lötdrahtes!
Anschlussdrähte etwa 1 cm zwischen Sensor und Platine lassen, damit der Sensor in die richtige Position am Platinenrand gebracht werden kann.

CR2032 probeweise wieder einsetzen, Spannung am Pin 1 von IC1 messen, mit einem Magneten sich dem Sensor nähern, die Spannung muss auf etwa Null Volt sinken und wieder auf VDD steigen, wenn der Magnet entfernt wird.

CR2032 wieder entfernen und IC1 einsetzen, CMOS Bausteine erfordern Schutz gegen statisches Aufladen!

Die Knopfzelle wieder einsetzen, an SDA und SCL muss VDD anliegen.

Einen ESP8266 (D1 mini)entsprechend anschließen und mit einem I²C Scanner den RTC Baustein suchen, er sollte auf der Hex Adresse 50 zu finden sein.

Falls kein I²C Scanner vorhanden ist, kann auch das Leseprogramm verwendet werden, es sollte über den seriellen Monitor Fehlermeldung ausgeben, wenn der RTC Baustein nicht gefunden wird.

Gegenfalls Verdrahtung von SDA, SCL und GND prüfen.

Bemerkung:

Der Sensor kann über seinen 3V3in-Anschluss vom ESP8266 versorgt werden, in diesem Fall den 3V3 Anschluss des ESP8266 mit 3v3in verbinden. Die Knopfzelle kann auf der Sensorplatine bleiben, die Versorgungsspannungen sind über die Dioden D1 und D2 entkoppelt. Durch den Spannungsabfall von etwa 0,6V über die Diode D1 bleibt die Spannung im sicheren Bereich.

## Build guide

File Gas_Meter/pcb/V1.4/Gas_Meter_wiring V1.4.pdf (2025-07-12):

ESP8266 Wiring Diagram

WEMOS D1 mini - Top View

RTC
Reset | RST | | TX | TXD
Analog IN | A0 | | RX | RXD
GPIO16 | D0 | | D1 | GPIO05 | SCL
GPIO14 | D5 | ESP8266 | D2 | GPIO04 | SDA
UPDATE_PIN | GPIO12 | D6 | D3 | GPIO00
RESET_PIN | GPIO13 | D7 | D4 | GPIO02
GPIO15 | D8 | | GND | | GND
3,3 Volt | 3V3 | | 5V
| | USB

Connect GPIO12 to GND to temporarily prevent sleep and allow MQTT to send commands Connect GPIO12 to GND to reset the ESP and the RTC IC
Connect GPIO16 to RST to wake up from deep sleep

Connect the fully assembled RTC PCB to SDA, SCL and GND of the ESP8266, insert coin cell CR2032. Connect the VDD terminal on the PCB to 3V3 of ESP8266.

To initialize the RTC Chip, connect GPIO13 (D7 on WEMOS D1 mini) to ground. Reset the ESP8266 and the RTC init routine will be called in the setup function and the program loop. Remove the connection once the init is done.

The init procedure has to be repeated after power loss of the CR2032 battery.

If you want to send MQTT commands to a sleeping ESP8266, connect GPIO12 (D6 on WEMOS D1 mini) to GND and wait for next wake up. Send the required commands, watch the execution on a MQTT Explorer and remove the connection once all commands are properly executed.

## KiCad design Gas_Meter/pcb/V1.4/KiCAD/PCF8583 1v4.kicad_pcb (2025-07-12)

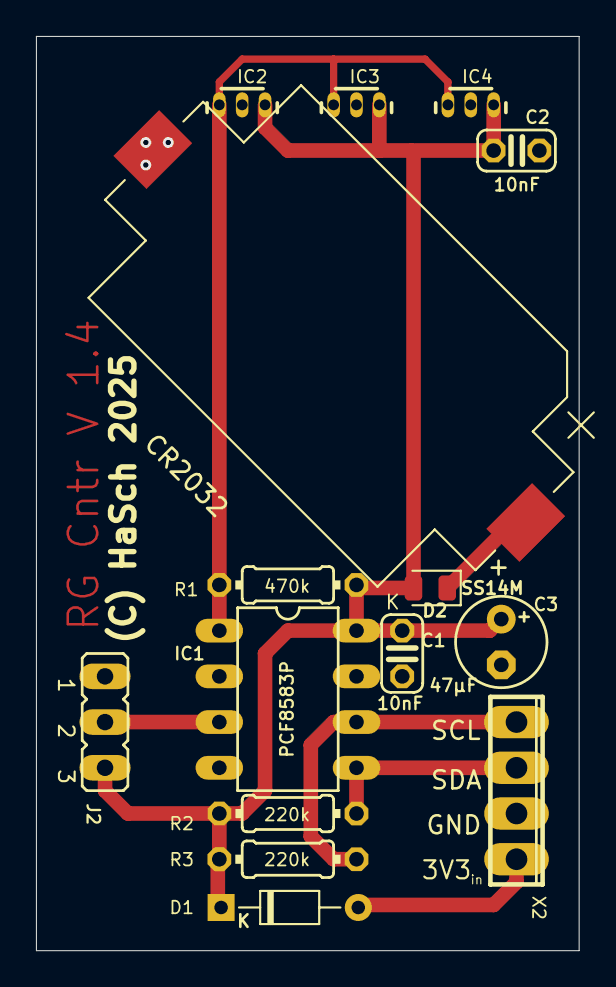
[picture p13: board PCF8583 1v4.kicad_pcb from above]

Board: 2 copper layers, 30.2 x 50.8 mm, 15 parts (0 on the bottom side), 7 nets.

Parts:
C1, C2: 10nF; C025-024X044
C3: 47µF; E2,5-5
CR2032: BatteryHolder_Keystone_1060_1x2032
D1: 1N4148; D_DO-34_SOD68_P7.62mm_Horizontal
D2: SS14M; D_0805_2012Metric
IC1: PCF8583P; DIL08
IC2, IC3, IC4: A1301UA; SIP3-UA
J2: JP2
R1: 470k; 0204_7
R2, R3: 220k; 0204_7
X2: 4POL254

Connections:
CNT: IC1.1, IC2.3, IC3.3, IC4.3, R1.1
GND: C1.2, C2.2, C3.-, CR2032.2, IC1.4, IC2.2, IC3.2, IC4.2, J2.1, X2.3
unnamed: D1.2, X2.4
unnamed: IC1.3, J2.2
SCL: IC1.6, R3.1, X2.1
SDA: IC1.5, R2.1, X2.2
VDD: C1.1, C2.1, C3.+, D1.1, D2.2, IC1.8, IC2.1, IC3.1, IC4.1, J2.3, R1.2, R2.2, R3.2

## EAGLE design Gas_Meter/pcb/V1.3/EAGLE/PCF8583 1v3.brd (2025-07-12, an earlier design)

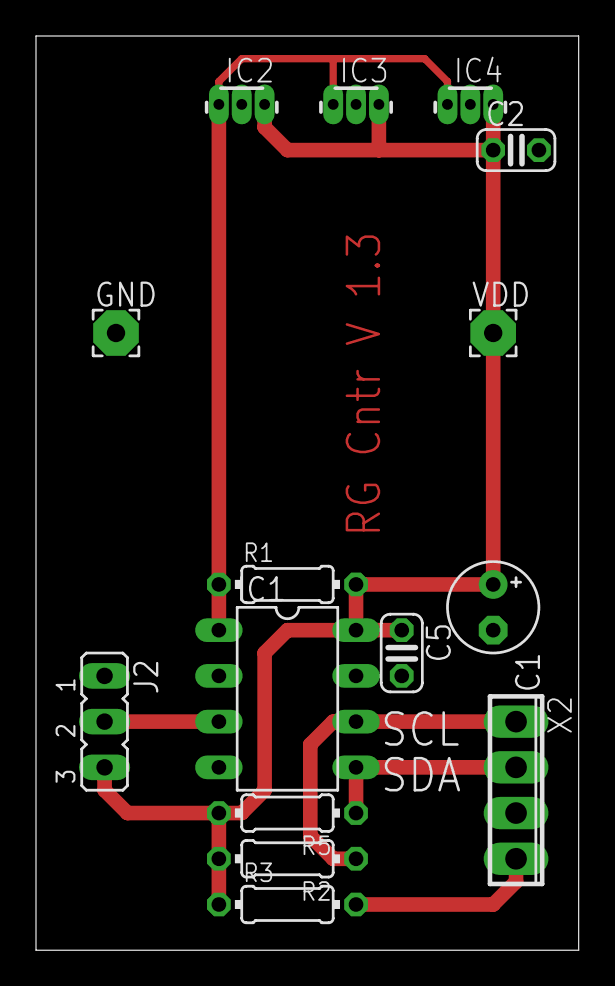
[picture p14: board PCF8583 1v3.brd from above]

Board: 2 copper layers, 30.1 x 50.8 mm, 15 parts (0 on the bottom side), 7 nets.

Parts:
C1: 47µF; E2,5-5
C2, C5: 10nF; C025-024X044
GND: 2,54/1,0
IC1: PCF8583P; DIL08
IC2, IC3, IC4: A1301UA; SIP3-UA
J2: JP2
R1: 470k; 0204/7
R2, R5: 220k; 0204/7
R3: 10k; 0204/7
VDD: 2,54/1,0
X2: 4POL254

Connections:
CNT: IC1.1, IC2.3, IC3.3, IC4.3, R1.1
GND: C1.-, C2.2, C5.2, GND.1, IC1.4, IC2.2, IC3.2, IC4.2, J2.1, X2.3
unnamed: R3.2, X2.4
unnamed: IC1.3, J2.2
SCL: IC1.6, R2.1, X2.1
SDA: IC1.5, R5.1, X2.2
VDD: C1.+, C2.1, C5.1, IC1.8, IC2.1, IC3.1, IC4.1, J2.3, R1.2, R2.2, R3.1, R5.2, VDD.1

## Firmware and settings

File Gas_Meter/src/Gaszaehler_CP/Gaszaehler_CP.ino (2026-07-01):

/**************************************************************************/
/*
  Gas counter using RTC as counter and storing values in RAM
  (c) Hans Schneider 2026 
  V1.4.2 (final compact DS1307 RAM layout)
  30.06.2026
  forked from /Rainer-G/Gas_Meter
  Board: Lolin(Wemos) D1 R2 & mini oder D1 mini pro
*/
/**************************************************************************/
#define THINGSPEAK                                                        // if you want to send data to the Internet
// #define debugserial                                                    // uncomment if you would like to see debug lines in serial monitor
// #define debugmqtt                                                      // uncomment if you would like to see debug lines over MWTT

#include <Wire.h>
#include <PicoMQTT.h>
#include "Gas_WiFi.h"
#include "Gas_MQTT.h"
#include "Gas_Time.h"
#include <ArduinoOTA.h>
#ifdef THINGSPEAK
  #include "Gas_Thingspeak.h"
#endif

#define RESET_PIN                  D7                                     // LOW will reset the counter and clear old data
#define UPDATE_PIN                 D6                                     // LOW will prevent going to sleep, needed for MQTT Commands & OTA updates

#define COUNTER_MODE               0x20                                   // counter mode 0x20
#define COUNTER_ADDRESS            0x50                                   // 7 I²C bit address for RTC Chip
#define CONTROL_ADDRESS            0x00
#define ADDRESS_COUNTER            0x01                                   // only 3 bytes with 6 BCD digits

#define FLAG_VALID                 0xA5
#define RAM_BASE                   0x08                                   // DS1307 free RAM: 0x08..0x3F

#define ADDRESS_OLD_COUNTER        (RAM_BASE + 0)                         // 4 Byte

#define ADDRESS_START_METER        (RAM_BASE + 4)                         // 4 Byte
#define ADDRESS_START_METER_FLAG   (ADDRESS_START_METER + 4)

#define ADDRESS_START_PERIOD       (RAM_BASE + 9)                         // 4 Byte
#define ADDRESS_START_PERIOD_FLAG  (ADDRESS_START_PERIOD + 4)

#define ADDRESS_DAY_START_COUNT    (RAM_BASE + 14)                        // 4 Byte
#define ADDRESS_DAY_DATE           (RAM_BASE + 18)                        // 3 Byte
#define ADDRESS_DAY_INITIALIZED    (RAM_BASE + 21)                        // 1 Byte
#define ADDRESS_DAY_STATE          (RAM_BASE + 22)                        // 1 Byte

#define ADDRESS_MONTHS_VALID       (RAM_BASE + 23)                        // 1 Byte
#define ADDRESS_MONTH_01           (RAM_BASE + 24)                        // 12 x 2 Byte = 24 Byte

#ifdef debugmqtt
  #define MQTT_DEBUG_NEW_COUNT       "debug/new_count"
  #define MQTT_DEBUG_DAY_START_COUNT "debug/day_start_count"
  #define MQTT_DEBUG_DAILY_COUNT     "debug/daily_count"
  #define MQTT_DEBUG_DAY_INIT        "debug/day_initialized"
  #define MQTT_DEBUG_DATE            "debug/date"
  #define MQTT_DEBUG_TIME            "debug/time"
  #define MQTT_DEBUG_TAG             "debug/tag"
#endif

// Global runtime state
bool      error               = false;            // report error to MQTT
bool      log_msg             = true;             // for Test only, set to false when in operation

uint32_t  old_time;                               // in seconds
uint32_t  new_time;                               // in seconds

uint32_t  old_count           = 0;
uint32_t  new_count           = 0;
uint32_t  delta_count         = 0;

uint32_t  liter_per_count     = 10;               // see meter label
float     mexp3_per_count     = 0.01;             // see meter label
double    brennwert           = 11.688629;        // 11.53800
double    zustandszahl        = 0.93940;          // 0.93940
uint16_t  year_offset         = 2000;

float     energy1             = 0;                // current load in kWh
double    total_energy        = 0;                // total usage in kWh

uint32_t  start_consumption   = 0;                // set after first start or battery change
double    consumption         = 0;                // Gas in liter
uint32_t  start_period        = 0;                // Gas in liter
uint32_t  period              = 0;                // in seconds

String    consumption_string  = "";               // temp string for a monthly consumption

uint32_t  day_start_count     = 0;                // start value for normal daily counting
uint32_t  daily_count         = 0;                // calculated daily counter
double    daily_consumption_l = 0;
double    daily_volume_m3     = 0;
double    daily_energy_kWh    = 0;
uint8_t   day_initialized     = 0;

#define DAY_STATE_NORMAL           0
#define DAY_STATE_MANUAL_RESET     1

uint8_t   day_state = DAY_STATE_NORMAL;

char      valueString1[ 80 ];
char      valueString2[ 80 ];
char      valueString3[ 80 ];
char      valueString4[ 80 ];
char      valueString5[ 80 ];
char      valueString6[ 80 ];
char      valueString7[ 80 ];
char      valueString8[ 80 ];
char      valueString9[ 80 ];
char      valueString10[ 80 ];
char      valueString11[ 80 ];
char      valueString12[ 80 ];
char      valueString13[ 80 ];

uint8_t old_hour;
uint8_t old_min;
uint8_t old_sec;

// Helper unions for byte conversion
union long_t
{
  uint32_t long_data;
  uint8_t  byte_data[ 4 ];
};

union int_t
{
  uint16_t int_data;
  uint8_t  byte_data[ 2 ];
};

// Convert BCD to decimal
uint8_t bcd2byte( uint8_t value )
{
  return (( value >> 4 ) * 10 ) + ( value & 0x0f );
}

// Convert decimal to BCD
uint8_t byte2bcd( uint8_t value )
{
  return (( value / 10) << 4 ) + ( value % 10 );
}

// Set counter mode on the RTC counter chip
bool set_Counter_Mode( )
{
  Wire.beginTransmission( COUNTER_ADDRESS );
  Wire.write( CONTROL_ADDRESS );
  Wire.write( COUNTER_MODE );
  return ( Wire.endTransmission( true ) == 0 );
}

// Read control register
uint8_t get_Mode( )
{
  return get_Byte( CONTROL_ADDRESS );
}

// Write one byte to RTC RAM
bool set_Byte( int8_t address, int8_t value )
{
  Wire.beginTransmission( COUNTER_ADDRESS );
  Wire.write( address );
  Wire.write( value );
  return ( Wire.endTransmission( true ) == 0 );
}

// Read one byte from RTC RAM
int8_t get_Byte( int8_t address )
{
  Wire.beginTransmission( COUNTER_ADDRESS );
  Wire.write( address );
  Wire.endTransmission( );
  Wire.requestFrom( COUNTER_ADDRESS, 1 );
  return Wire.read( );
}

// Write 2 bytes to RTC RAM
bool set_Integer( int8_t address, int16_t value )
{
  int_t temp_data;
  temp_data.int_data = value;
  Wire.beginTransmission( COUNTER_ADDRESS );
  Wire.write( address );
  Wire.write( temp_data.byte_data[ 0 ] );
  Wire.write( temp_data.byte_data[ 1 ] );
  return ( Wire.endTransmission( true ) == 0 );
}

// Read 2 bytes from RTC RAM
bool get_Integer( int8_t address, int16_t &value )
{
  int_t temp_data;
  value = 0;
  Wire.beginTransmission( COUNTER_ADDRESS );
  Wire.write( address );
  Wire.endTransmission( );
  byte len = Wire.requestFrom( COUNTER_ADDRESS, 2 );
  if ( len == 0 )
  {
    #ifdef debugserial
      Serial.println("");
      Serial.println("***************** Error occured when reading 2 bytes ******************");
    #endif
    return false;
  }
  temp_data.byte_data[ 0 ] = Wire.read( );
  temp_data.byte_data[ 1 ] = Wire.read( );
  value = temp_data.int_data;
  return true;
}

// Write 4 bytes to RTC RAM
bool set_My_4_bytes( int8_t address, int32_t value )
{
  union long_t temp_data;
  temp_data.long_data = value;
  Wire.beginTransmission( COUNTER_ADDRESS );
  Wire.write( address );
  Wire.write( temp_data.byte_data[ 0 ] );
  Wire.write( temp_data.byte_data[ 1 ] );
  Wire.write( temp_data.byte_data[ 2 ] );
  Wire.write( temp_data.byte_data[ 3 ] );
  return ( Wire.endTransmission( true ) == 0 );
}

// Read 4 bytes from RTC RAM
bool get_My_4_bytes( int8_t address, uint32_t &value )
{
  long_t temp_data;
  value = 0;
  Wire.beginTransmission( COUNTER_ADDRESS );
  Wire.write( address );
  Wire.endTransmission( );
  byte len = Wire.requestFrom( COUNTER_ADDRESS, 4 );
  if ( len == 0 )
  {
    #ifdef debugserial
      Serial.println("");
      Serial.println("********************* Error occured when reading My 4 bytes **************");
    #endif
    return false;
  }
  temp_data.byte_data[ 0 ] = Wire.read( );
  temp_data.byte_data[ 1 ] = Wire.read( );
  temp_data.byte_data[ 2 ] = Wire.read( );
  temp_data.byte_data[ 3 ] = Wire.read( );
  value = temp_data.long_data;
  return true;
}

// Read the external counter value
bool get_Counter( int8_t address, uint32_t &count  )
{
  count = 0;
  Wire.beginTransmission( COUNTER_ADDRESS );
  Wire.write( address );
  Wire.endTransmission( );
  byte len = Wire.requestFrom( COUNTER_ADDRESS, 3 );
  if ( len == 0 )
  {
    #ifdef debugserial
      Serial.println("");
      Serial.println("********************* Error occured when reading Counter *****************");
    #endif
    return false;
  }

  uint8_t b1 = Wire.read();
  uint8_t b2 = Wire.read();
  uint8_t b3 = Wire.read();

  count = bcd2byte( b1 );
  count = count + bcd2byte( b2 ) * 100L;
  count = count + bcd2byte( b3 ) * 10000L;
  return true;
}

// Write counter value in BCD format
bool set_Counter( int8_t address, int32_t value )
{
  Wire.beginTransmission( COUNTER_ADDRESS );
  Wire.write( address );
  Wire.write( byte2bcd(   value % 100L ));
  Wire.write( byte2bcd( ( value / 100L ) % 100L ));
  Wire.write( byte2bcd( ( value / 10000L ) % 100L ));
  return ( Wire.endTransmission( true ) == 0 );
}

// Read time from RTC RAM
void get_Time( int8_t address, uint8_t &o_hour, uint8_t &o_min, uint8_t &o_sec )
{
  Wire.beginTransmission( COUNTER_ADDRESS );
  Wire.write( address );
  Wire.endTransmission( );
  Wire.requestFrom( COUNTER_ADDRESS, 3 );
  o_hour   = Wire.read( );
  o_min    = Wire.read( );
  o_sec    = Wire.read( );
}

// Write time to RTC RAM
bool set_Time( int8_t address, uint8_t o_hour, uint8_t o_min, uint8_t o_sec )
{
  Wire.beginTransmission( COUNTER_ADDRESS );
  Wire.write( address );
  Wire.write( o_hour );
  Wire.write( o_min );
  Wire.write( o_sec );
  return ( Wire.endTransmission( true ) == 0 );
}

// Check of plausibility
bool validDate(uint8_t d, uint8_t m, uint16_t y)
{
  return (d >= 1 && d <= 31 && m >= 1 && m <= 12 && y >= 2000 && y <= 2099);
}

// Write date to RTC RAM
bool set_Date( int8_t address, uint8_t day, uint8_t month, int year )
{
  Wire.beginTransmission( COUNTER_ADDRESS );
  Wire.write( address );
  Wire.write( day );
  Wire.write( month );
  year = year - year_offset;
  Wire.write( (uint8_t)year );
  return ( Wire.endTransmission( true ) == 0 );
}

// Read date from RTC RAM
void get_Date( int8_t address, uint8_t &day, uint8_t &month, uint16_t &year )
{
  Wire.beginTransmission( COUNTER_ADDRESS );
  Wire.write( address );
  Wire.endTransmission();
  Wire.requestFrom( COUNTER_ADDRESS, 3 );
  day   = Wire.read();
  month = Wire.read();
  year  = Wire.read() + year_offset;
}

// Check if months are valid
bool months_valid()
{
  return get_Byte(ADDRESS_MONTHS_VALID) == FLAG_VALID;
}

void set_months_valid(bool ok)
{
  set_Byte(ADDRESS_MONTHS_VALID, ok ? FLAG_VALID : 0x00);
}

bool valid_month_value(uint16_t value)
{
  return value <= 60000;
}

// Write 4-byte value and flag
bool set_My_4_bytes_with_flag(int8_t address, uint32_t value, int8_t flag_address)
{
  bool ok = set_My_4_bytes(address, value);
  if (ok) ok = set_Byte(flag_address, FLAG_VALID);
  return ok;
}

// Read 4-byte value only if flag is valid
bool get_My_4_bytes_with_flag(int8_t address, int8_t flag_address, uint32_t &value)
{
  uint8_t flag = get_Byte(flag_address);
  if (flag != FLAG_VALID)
  {
    value = 0;
    return false;
  }
  return get_My_4_bytes(address, value);
}

// Save the start count for a month
bool set_month(int8_t month, uint16_t current_count)
{
  if (month < 1 || month > 12) return false;
  uint8_t month_address = ADDRESS_MONTH_01 + (month - 1) * 2;
  bool ok = set_Integer(month_address, (int16_t)current_count);
  if (ok) set_months_valid(true);
  return ok;
}

// Read the start count for a month
bool get_month(int8_t month, uint16_t &current_count)
{
  if (month < 1 || month > 12) return false;
  if (!months_valid()) return false;

  uint8_t month_address = ADDRESS_MONTH_01 + (month - 1) * 2;
  int16_t tmp = 0;
  if (!get_Integer(month_address, tmp)) return false;

  current_count = (uint16_t)tmp;
  return valid_month_value(current_count);
}

//
//**************************************************************************************************
//                                          L O G P R I N T                                        *
//**************************************************************************************************
// Log messages if log_msg is true                                                                 *
// Uses vsnprint for format strings, needs /r/n for CR/LF at end                                   *
//**************************************************************************************************
//
// Simple logging helper
char* logprint ( const char* format, ... )
{
  static char sbuf[ 128 ];                             // For debug lines
  va_list varArgs;                                     // For variable number of params
  va_start ( varArgs, format );                        // Prepare parameters
  vsnprintf ( sbuf, sizeof(sbuf), format, varArgs );   // Format the message
  va_end ( varArgs );                                  // End of using parameters
  if ( log_msg ) Serial.print ( sbuf );                // Log Messages on? Info
  return sbuf;                                         // Return stored string
}

// Initialize the hardware counter and time base
void init_counter()
{
  set_Counter_Mode();
  set_Counter( ADDRESS_COUNTER, 0 );
  set_My_4_bytes( ADDRESS_OLD_COUNTER, 0 );
}

// Initialize the day counter
void init_day_counter()
{
  day_state = DAY_STATE_MANUAL_RESET;

  day_start_count = new_count;
  daily_count = 0;
  daily_consumption_l = 0;
  daily_volume_m3 = 0;
  daily_energy_kWh = 0;

  set_My_4_bytes(ADDRESS_DAY_START_COUNT, day_start_count);

  // Check of plausibility
  if (validDate(Gas_day, Gas_month, Gas_year))
  {
    set_Date(ADDRESS_DAY_DATE, Gas_day, Gas_month, Gas_year);
  }
  set_Byte(ADDRESS_DAY_INITIALIZED, 1);
  set_Byte(ADDRESS_DAY_STATE, DAY_STATE_MANUAL_RESET);

  #ifdef debugmqtt
    publish_topic("debug/day_start_count", String(day_start_count));
    publish_topic("debug/daily_count", "0");
    publish_topic("debug/day_initialized", "1");
  #endif  

  MQTT_command = "";
}

// Publish one or all monthly counters
void publish_month( )
{
  uint8_t  cmd_month = 0;
  uint8_t  cmd_value = 0;
  uint8_t  cmd_start = 0;
  uint8_t  cmd_end   = 0;
  uint16_t month_start_count = 0;
  uint32_t month_consumption = 0;
  String   value3;

  consumption_string = MQTT_command.substring( MQTT_command.indexOf(',') + 1);
  cmd_value          = consumption_string.toInt();
  cmd_month          = constrain( cmd_value, 1, 12 );
  value3             = "";

  if ( cmd_value <= 12 )
  {
    cmd_start = cmd_month;
    cmd_end   = cmd_month;
  }
  else
  {
    cmd_start = 1;
    cmd_end   = 12;
  }

  for ( int i = cmd_start; i <= cmd_end; i++ )
  {
    if ( get_month(i, month_start_count) )
    {
      month_consumption = ( new_count >= month_start_count ) ? ( new_count - month_start_count ) * liter_per_count : 0;
    }
    else
    {
      month_consumption = 0;
    }
    value3 = value3 + ';' + String( i ) + ';' + String( month_consumption );
  }

  publish_topic( "month_data", value3 );
  MQTT_command  = "";
}

// Save period start
void set_period( )
{
  uint32_t cmd_data = 0;
  String value3;
  if ( MQTT_command.indexOf(',') > 0 )
  {
    value3 = MQTT_command.substring( MQTT_command.indexOf(',') + 1);
    cmd_data = value3.toInt();
  }
  set_My_4_bytes( ADDRESS_START_PERIOD, cmd_data );
  set_Byte(ADDRESS_START_PERIOD_FLAG, FLAG_VALID);
  start_period = cmd_data;
  MQTT_command = "";
}
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
void loop()
{
  mqtt.loop();
  ArduinoOTA.handle();                  // keep OTA responsive

  error = false;

  if (WiFi.status() != WL_CONNECTED)
    Gas_WiFi_reconnect();

  if (MQTT_command != "")
    command_parser();

  if (get_My_4_bytes(ADDRESS_OLD_COUNTER, old_count) != true)
    old_count = 0;

  if (get_Counter(ADDRESS_COUNTER, new_count) != true)
  {
    error = true;
    new_count = 0;
  }

  if (!get_LocalTime())
    return;

  uint8_t stored_day = 0;
  uint8_t stored_month = 0;
  uint16_t stored_year = 0;

  get_Date(ADDRESS_DAY_DATE, stored_day, stored_month, stored_year);

  // Restore valid values if stored values are corrupt
  if (!validDate(stored_day, stored_month, stored_year))
  {
    #ifdef debugmqtt
      publish_topic("debug/day_change", "before correction: ");
      publish_topic("debug/day_change", "Gas_date: " + String(Gas_day) + "." + String(Gas_month) + "." + String(Gas_year));
      publish_topic("debug/day_change", "stored_date: " + String(stored_day) + "." + String(stored_month) + "." + String(stored_year));
        #endif
    stored_day = Gas_day;
    stored_month = Gas_month;
    stored_year = Gas_year;
    #ifdef debugmqtt
      publish_topic("debug/day_change", "after correction: ");
      publish_topic("debug/day_change", "Gas_date: " + String(Gas_day) + "." + String(Gas_month) + "." + String(Gas_year));
      publish_topic("debug/day_change", "stored_date: " + String(stored_day) + "." + String(stored_month) + "." + String(stored_year));
    #endif
    set_Date(ADDRESS_DAY_DATE, stored_day, stored_month, stored_year);
    set_My_4_bytes(ADDRESS_DAY_START_COUNT, new_count);
    day_start_count = new_count;
    daily_count = 0;
    day_initialized = 1;
    day_state = DAY_STATE_NORMAL;
    set_Byte(ADDRESS_DAY_INITIALIZED, 1);
    set_Byte(ADDRESS_DAY_STATE, DAY_STATE_NORMAL);
    #ifdef debugmqtt
      publish_topic("debug/day_change", "invalid date -> init");
    #endif
  }
  else if ((Gas_day != stored_day) || (Gas_month != stored_month) || (Gas_year != stored_year))
  {
    day_start_count = new_count;
    daily_count = 0;
    set_My_4_bytes(ADDRESS_DAY_START_COUNT, day_start_count);
    set_Date(ADDRESS_DAY_DATE, Gas_day, Gas_month, Gas_year);
    #ifdef debugmqtt
      publish_topic("debug/day_change", "day change");
      publish_topic("debug/day_change", "Gas_date: " + String(Gas_day) + "." + String(Gas_month) + "." + String(Gas_year));
      publish_topic("debug/day_change", "stored_date: " + String(stored_day) + "." + String(stored_month) + "." + String(stored_year));
      publish_topic("debug/day_change", "day_start_count: " + String(day_start_count));
      publish_topic("debug/day_change", "new_count: " + String(new_count));
    #endif
  }
  else
  {
    // Correction of any implausible condition
    if (day_start_count > new_count)
      day_start_count = new_count;

    daily_count = new_count - day_start_count;
    #ifdef debugmqtt
      publish_topic("debug/day_change", "no day change");
      publish_topic("debug/day_change", "Gas_date: " + String(Gas_day) + "." + String(Gas_month) + "." + String(Gas_year));
      publish_topic("debug/day_change", "stored_date: " + String(stored_day) + "." + String(stored_month) + "." + String(stored_year));
      publish_topic("debug/day_change", "day_start_count: " + String(day_start_count));
      publish_topic("debug/day_change", "new_count: " + String(new_count));
    #endif
  }

  daily_consumption_l = daily_count * liter_per_count;
  daily_volume_m3     = daily_count * mexp3_per_count;
  daily_energy_kWh    = daily_count * mexp3_per_count * brennwert * zustandszahl;

  #ifdef debugmqtt
    publish_debug_topics("after_daily_calc");
  #endif

  // Save previous counter/time/date for the next loop iteration
  set_My_4_bytes(ADDRESS_OLD_COUNTER, new_count);

  consumption  = (start_consumption + new_count * liter_per_count) / 1000.0;
  total_energy = consumption * brennwert * zustandszahl;
  energy1      = (double)delta_count * (double)mexp3_per_count * brennwert * zustandszahl;

  dtostrf(total_energy, 12, 3, valueString1);
  dtostrf(energy1, 12, 3, valueString2);
  dtostrf(consumption, 12, 3, valueString3);
  dtostrf(new_count, 10, 0, valueString4);
  dtostrf(energy1, 12, 3, valueString5);
  dtostrf(start_consumption / 1000.0, 12, 3, valueString6);
  dtostrf(start_period / 1000.0, 12, 3, valueString7);
  dtostrf(daily_consumption_l, 12, 0, valueString9);
  dtostrf(daily_volume_m3, 12, 3, valueString10);
  dtostrf(daily_energy_kWh, 12, 3, valueString11);
  sprintf(valueString8, "%02d:%02d:%02d", Gas_hour, Gas_min, Gas_sec);

  // Publish to Thingspeak
  #ifdef THINGSPEAK
    ThingSpeak.setField(1, valueString1);
    ThingSpeak.setField(2, valueString2);
    ThingSpeak.setField(3, valueString3);
    ThingSpeak.setField(4, valueString4);
    ThingSpeak.setField(5, valueString5);
    ThingSpeak.setField(6, valueString9);
    ThingSpeak.setField(7, valueString10);
    ThingSpeak.setField(8, valueString11);
    Send_data();
  #endif

  publish_topic("Time",          valueString8);
  publish_topic("Total_kWh",     valueString1);
  publish_topic("Power_kW",      valueString5);
  publish_topic("Counts",        valueString4);
  publish_topic("Volume",        valueString3);
  publish_topic("Start",         valueString6);
  publish_topic("Period_Start",  valueString7);
  publish_topic("Daily_Liter",   valueString9);
  publish_topic("Daily_m3",      valueString10);
  publish_topic("Daily_kWh",     valueString11);
  publish_topic("Status",        error == true ? "Error" : "OK");

  if (digitalRead(UPDATE_PIN) == HIGH)
  {
    delay(1000);
    ESP.deepSleep(111 * 1000 * 1000);
  }
  else
  {
    delay(3000);
  }
}

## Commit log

2026-06-10 OTA added, Daily Counts added, Monthly values corrected
    [Gaszaehler_CP.ino]
2026-06-10 Update print statement from 'Hello' to 'Goodbye'
2026-06-10 Update fmt.Println output from 'Hello' to 'Goodbye'
2026-06-10 Update README with ArduinoOTA instructions
    Added instructions for ArduinoOTA hashed value in README.
2026-06-10 Fix formatting in README for ArduinoOTA section
2026-06-23 Update Gaszaehler_CP.ino
    At the start of the new billing period, an old initial consumption value is no longer carried over.
    [Gaszaehler_CP.ino]
2026-06-26 The day counter is now resettable. Comment lines have been added to improve code readability.
    [Gaszaehler_CP.ino]
2026-06-27 Improvement of detecting the deep sleep mode block (D6 connected to GND)
2026-06-29 Now (hopefully) the last bug has been fixed.
    [Gaszaehler_CP.ino]
